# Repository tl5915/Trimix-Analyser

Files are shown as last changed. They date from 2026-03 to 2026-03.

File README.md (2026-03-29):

# Trimix Analyser
Trimix analyser for scuba diving

## Material
### Housing
- Electronic junction box 158x90x60mm
- 15 mm ID, 18 mm OD PVC pipe (for sensor chamber, O2 mount to the end, He and CO on two sides, gas out on the other end)
- M16 x 1.0 tap (for O2 sensor)
- 16 mm ID silicone plug (drill hole for gas out)
- BCD nipple to 1.4 NPT male convertor (gas in)
- 3/8 UNF tap (tap on the NPT side of the above convertor to mount a o-ring-removed LP blanking plug to adjust flow rate to 2 L/min)
- 1/4 NPT female to the smallest hose barb you can find, use barb convertor if necessary (ideally 2 mm ID silicone tubing connect to sensor chamber)
### Electronics
- Oxygen sensor, Aux or Molex connector He Sensor
- Wisen MD62 Helium sensor (mount to sensor chamber with hole cut out and seal with epoxy)
- 1N5819 Schottky diode (drops the 3.3v to 3.0v that MD62 requires)
- DS3502 digital potentiometer (10k ohm), parallel connect to 510 ohm resistor to drop total resistence to 485 ohm
- 2k ohm resistors for MD62 wheastone bridge
- 47k ohm 1:1 voltage divider to monitor MD62 Vcc Gas Quality Sensor
- SGP40 gas sensor (drill hole to fit sensor into sensor chamber, seal with epoxy)
- Use JST-SH cable to connect to DS3502, provides power and I2C communication MCU and Display
- Seeed Xiao ESP32C3
- 1.3 inch I2C SH1106 OLED
- ADS1115 ADC
### Power
- 3.7V 2000 mAh LiPo battery
- TP4056 LiPo charging board
- Qi wireless charging receiver unit
- Sparkfun Soft Power Switch (connect to external momentary button, connect push and off to GPIO pins)
- Momentary button for calibration and power
- 3.3V buck-boost converter (at least 250mA output capacity)
- 100nF capacitors at converter input and output
- 47k ohm 1:1 voltage divider to monitor battery voltage

## Button logic
- Press and hold button for 1 second to power on
- In main page, single press to enter menu
- Short press to toggle, long press to select
- Press and hold for 5 seconds to power off
- Press and hold for 10 seconds will force the switch to hardware power off
- Automatic power off after 5 minutes if no button press

## WiFi
- Default off to save power, can be turned on in setting menu
- Connect WiFi hotspot and scan the QR code to see more data, maunally input calibration values, and OTA firmware upgrade
- WiFi transmission power is set to minimum, external antenna must be connected

## Usage
- Reverse helium polarity in setting menu if helium voltage is negative in trimix
- Use pure helium or standard gas trimix for helium calibration
- SGP40 reading at top middle of the display, only shows after 1 minute initialisation. This reading is not in PPM, but relative to fresh air (100), lower (towards 1) the better quality, higher (towards 500) the worse quality. Volatile organic compounds, CO, and CO2 (all gases you don't want in your cylinder) increases reading
- Connect to WiFi, scan QR code to open web page
- More sensor informations can be found on web page, also allow maunal overwrite of calibration values
- Upload .bin file for OTA firmware update

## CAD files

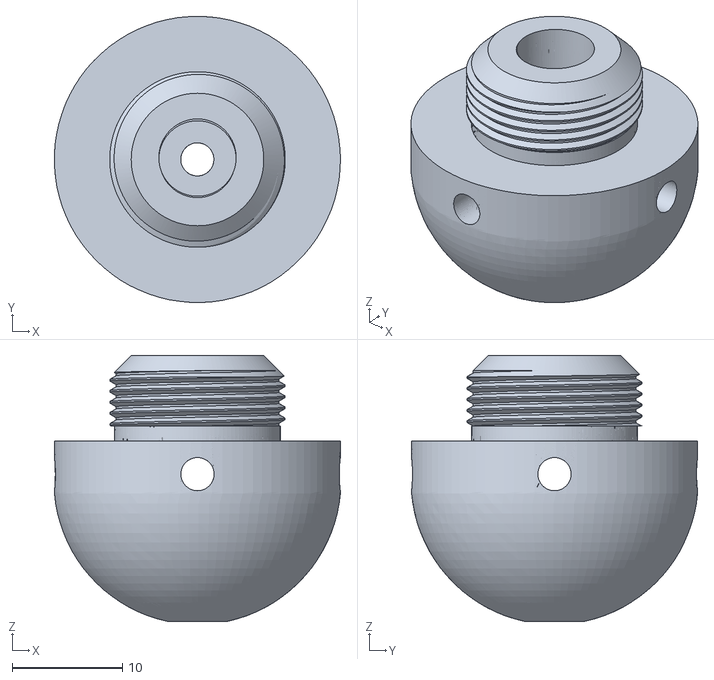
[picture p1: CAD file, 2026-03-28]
Flow_restrictor.stl
25.9 x 25.9 x 24.1

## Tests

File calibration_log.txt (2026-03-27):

Calibration Log with known standard gas:
===============

12/67: 6.1mV / 371.7mV

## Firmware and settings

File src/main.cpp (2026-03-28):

#include <Arduino.h>
// OTA & UI Libraries
#include <WiFi.h>
#include <Update.h>
#include <esp_bt.h>
#include <esp_wifi.h>
#include <WebServer.h>
// Peripheral Libraries
#include <EEPROM.h>
#include <Adafruit_GFX.h>
#include <Adafruit_SH110X.h>
#include <Adafruit_DS3502.h>
#include <Adafruit_ADS1X15.h>
#include <SparkFun_SGP40_Arduino_Library.h>
#include <sensirion_arch_config.h>
#include <sensirion_voc_algorithm.h>
// HTML Pages
#include "html_page.h"
#include "manual_calibration_page.h"
// Bitmaps
#include "qr_code_bitmap.h"
#include "wifi_logo.h"

// Forward Declarations
void powerOffMode();
void airOxygenCalibration();
void zeroHeliumCalibration();
void pureOxygenCalibration();
void performHeliumCalibration();
void calibrationDisplay();
void resetToDefaultCalibration();
void enterSettingMode();
void setOxygenCalibration();
void setHeliumCalibration();
void setHeliumPolarity();
void setWiFi();
float getOxygenVoltage();
float getHeliumVoltage();

// Global Objects
SGP40 sgp40;
Adafruit_DS3502 ds3502;
Adafruit_ADS1115 ads;
Adafruit_SH1106G display(128, 64, &Wire);

// Pin Definition
const uint8_t SCLPin = D6;        // GPIO21, SCL
const uint8_t SDAPin = D5;        // GPIO 7, SDA
const uint8_t ADDRPin = D4;       // GPIO 6, ADS1115 Address
const uint8_t powerPin = D3;      // GPIO 5, Power off
const uint8_t batteryPin = A2;    // GPIO 4, Battery monitoring
const uint8_t MD62VccPin = A1;    // GPIO 3, MD62 input voltage monitoring
const uint8_t calButtonPin = D0;  // GPIO 2, Calibration button

// EEPROM Address
const int ADDR_HELIUM_POLARITY = 0;
const int ADDR_WIPER_VALUE = 4;
const int ADDR_OXYGEN_CAL_PERCENTAGE = 8;
const int ADDR_HELIUM_CAL_PERCENTAGE = 12;
const int ADDR_OXYGEN_CAL_VOLTAGE = 16;
const int ADDR_PURE_OXYGEN_VOLTAGE = 24;
const int ADDR_HELIUM_CAL_VOLTAGE = 32;
const int ADDR_WIFI_STATUS = 40;

// Calibration
const uint8_t defaultwiperValue = 57;           // Potentiometer wiper position
const uint8_t defaultOxygenCalPercentage = 99;  // Oxygen calibration percentage
const uint8_t defaultHeliumCalPercentage = 67;  // Helium calibration percentage
const float defaultOxygenCalVoltage = 9.38;     // Oxygen voltage in air
const float defaultPureOxygenVoltage = 49.75;     // Oxygen voltage in oxygen
const float defaultHeliumCalVoltage = 382.01;    // Helium voltage in helium
bool heliumPolarity = false;
bool isTwoPointCalibrated = false;
uint8_t wiperValue = defaultwiperValue;
uint8_t bestWiperValue = wiperValue;
uint8_t OxygenCalPercentage = defaultOxygenCalPercentage; 
uint8_t HeliumCalPercentage = defaultHeliumCalPercentage;
float oxygencalVoltage = defaultOxygenCalVoltage;
float pureoxygenVoltage = defaultPureOxygenVoltage;
float heliumcalVoltage = defaultHeliumCalVoltage;

// Sampling
const uint8_t calibrationSampleCount = 20;  // Average 20 samples for calibration
const uint8_t samplingRateHz = 50;          // Sampling rate 50 Hz
const uint8_t displayRateHz = 2;            // Display refresh rate 2 Hz
unsigned long lastSampleTime = 0;
unsigned long lastDisplayUpdate = 0;
uint16_t voc = 0;
uint16_t sgpRaw = 0;
uint16_t sgpRawCorr = 0;
uint16_t sampleCount = 0;
uint16_t avgSampleCount = 0;
float oxygenVoltage = 0.0;
float oxygenSum = 0.0;
float avgOxygenVoltage = 0.0;
float oxygenPercentage = 0.0;
float heliumVoltage = 0.0;
float heliumSum = 0.0;
float avgHeliumVoltage = 0.0;
float correctedHeliumVoltage = 0.0;
float heliumPercentage = 0.0;
float MD62Voltage = 0.0;
float MD62Sum = 0.0;
float avgMD62Voltage = 0.0;
float batteryVoltage = 0.0;
float batterySum = 0.0;
float avgBatteryVoltage = 0.0;
uint8_t batteryPercentage = 0;
uint16_t mod14 = 0;
uint16_t mod16 = 0;
uint16_t end = 0;
float den = 0.0;
bool sixnine = false;
unsigned long sixnineStartTime = 0;

// Calibration Button
const unsigned long debounceDelay = 50;        // Button debounce delay 50 ms
const unsigned long decisionWindow = 799;      // Short press threshold 799 ms
const unsigned long longPressDuration = 800;   // Long press threshold 800 ms
const unsigned long powerOffDuration = 3000;   // Power off threshold 3000 ms
const unsigned long powerOnDuration = 1000;    // Power on threshold 1000 ms
const unsigned long timeOutDuration = 900000;  // Power time out threshold 15 min
unsigned long lastButtonDebounceTime = 0;
unsigned long buttonPressStartTime = 0;
unsigned long lastButtonPressTime = 0;
bool isButtonPressed = false;
bool isShortPress = false;
bool isLongPress = false;
bool isPowerOff = false;
bool lastButtonState = false;

// WiFi Settings
const char *ssid = "trimix_analyser";  // WiFi SSID
const char *password = "12345678";     // WiFi password
WebServer server(80);                  // Web server on port 80
bool wifiEnabled = false;              // WiFi default off


// Calibration Button State
void checkCalibrationButton() {
  unsigned long currentTime = millis();
  bool currentButtonState = digitalRead(calButtonPin) == LOW;

  if (currentButtonState != lastButtonState) {
    lastButtonDebounceTime = currentTime;  // Reset debounce timer
  }

  if ((currentTime - lastButtonDebounceTime) > debounceDelay) {  // Button debounce
    if (currentButtonState) {  // Button pressed
      if (!isButtonPressed) {  // New press detected
        buttonPressStartTime = currentTime;
        isButtonPressed = true;
        isShortPress = false;
        isLongPress = false;
        isPowerOff = false;
      } else if (!isLongPress && (currentTime - buttonPressStartTime >= longPressDuration)) {  // Long press
        isShortPress = false;
        isLongPress = true;
        isPowerOff = false;
      } else if (!isPowerOff && (currentTime - buttonPressStartTime >= powerOffDuration)) {  // Power off
        isShortPress = false;
        isLongPress = false;
        isPowerOff = true;
        powerOffMode();
      }
    } else {  // Button is released
      if (isButtonPressed) {
        isButtonPressed = false;
        if (!isLongPress && (currentTime - buttonPressStartTime) <= decisionWindow) {  // Short press
          isShortPress = true;
        }
      }
    }
  }
  lastButtonState = currentButtonState;
}

// Calibration Mode
uint8_t calibrationOption = 0;
bool inCalibrationMode = false;
const uint8_t numCalibrationOptions = 8;
String getCalibrationOption(uint8_t index) {
  switch (index) {
    case 0: return "21% O2";
    case 1: return "0% He";
    case 2: return String(OxygenCalPercentage) + "% O2";
    case 3: return String(HeliumCalPercentage) + "% He";
    case 4: return "View";
    case 5: return "Reset";
    case 6: return "Setting";
    case 7: return "Exit";
    default: return "";
  }
}

void enterCalibrationMode() {
  isShortPress = false;
  isLongPress = false;
  inCalibrationMode = true;
  calibrationOption = 0;

  display.clearDisplay();
  display.setTextSize(2);
  display.setCursor(10, 24);
  display.print(F("Calibrate"));
  display.display();
  delay(500);

  while (inCalibrationMode) {
    display.clearDisplay();
    display.setTextSize(2);
    display.setCursor(10, 0);
    display.print(F("Calibrate"));
    display.drawLine(0, 18, 128, 18, SH110X_WHITE);

    display.setTextSize(1);
    for (uint8_t i = 0; i < numCalibrationOptions; i++) {
      if (i < 4) {  // Left column
        display.setCursor(0, 24 + (i * 10));
      } else {      // Right column
        display.setCursor(64, 24 + ((i - 4) * 10));
      }
      if (i == calibrationOption) {
        display.print(F("> "));
      } else {
        display.print(F("  "));
      }
      display.print(getCalibrationOption(i));
    }
    display.display();

    checkCalibrationButton();

    if (isShortPress) {        // Short press to move to next option
      isShortPress = false;
      calibrationOption = (calibrationOption + 1) % numCalibrationOptions;
    } else if (isLongPress) {  // Long press to select option
      isLongPress = false;
      switch (calibrationOption) {
        case 0:
          airOxygenCalibration();       // Perform 21% oxygen calibration
          break;
        case 1:
          zeroHeliumCalibration();      // Perform 0% helium calibration
          break;
        case 2:
          pureOxygenCalibration();      // Perform 100% oxygen calibration
          break;
        case 3:
          performHeliumCalibration();   // Perform 100% helium calibration
          break;
        case 4:
          calibrationDisplay();         // View calibration values
          break;
        case 5:
          resetToDefaultCalibration();  // Reset all calibrations
          break;
        case 6:
          enterSettingMode();           // Enter setting mode
          break;
        case 7:
          inCalibrationMode = false;    // Exit calibration mode
          break;
      }
    }
  }
}

// Calibration Mode - 21% Oxygen Calibration
void airOxygenCalibration() {
  while (true) {
    display.clearDisplay();
    display.setTextSize(1);
    display.setCursor(8, 18);
    display.print(F("21% Oxygen"));
    display.setCursor(8, 38);
    display.print(F("Calibrating..."));
    display.display();

    oxygenSum = 0.0;
    for (uint8_t i = 0; i < calibrationSampleCount; i++) {
      oxygenVoltage = getOxygenVoltage();
      oxygenSum += oxygenVoltage;
      delay(20);  // 50 Hz sampling rate
    }
    oxygencalVoltage = oxygenSum / calibrationSampleCount;

    display.clearDisplay();
    display.setTextSize(1);
    display.setCursor(8, 18);
    display.print(F("21% O2 Calibration"));
    display.setCursor(8, 38);
    display.print(oxygencalVoltage, 2);
    display.print(F(" mV"));
    display.display();

    while (true) {
      checkCalibrationButton();

      if (isShortPress) {        // Short press to repeat calibration
        isShortPress = false;
        break; 
      } else if (isLongPress) {  // Long press to save calibration
        isLongPress = false;

        EEPROM.put(ADDR_OXYGEN_CAL_VOLTAGE, oxygencalVoltage);
        EEPROM.commit();

        display.clearDisplay();
        display.setTextSize(1);
        display.setCursor(8, 28);
        display.print(F("Calibration Saved"));
        display.display();
        delay(500);

        inCalibrationMode = false;
        return;  // Exit calibration after saving
      }
    }
  }
}

// Calibration Mode - 100% Oxygen Calibration
void pureOxygenCalibration() {
  while (true) {
    display.clearDisplay();
    display.setTextSize(1);
    display.setCursor(8, 18);
    display.print(OxygenCalPercentage);
    display.print(F("% Oxygen"));
    display.setCursor(8, 38);
    display.print(F("Calibrating..."));
    display.display();

    oxygenSum = 0.0;
    for (uint8_t i = 0; i < calibrationSampleCount; i++) {
      oxygenVoltage = getOxygenVoltage();
      oxygenSum += oxygenVoltage;
      delay(20);  // 50 Hz sampling rate
    }
    pureoxygenVoltage = oxygenSum / calibrationSampleCount;

    if (pureoxygenVoltage <= oxygencalVoltage) {  // Invalid calibration
      while (true) {
        display.clearDisplay();
        display.setTextSize(2);
        display.setCursor(28, 20);
        display.print(F("Failed"));
        display.setTextSize(1);
        display.setCursor(22, 54);
        display.print(F("O2 Voltage Low"));
        display.display();

        checkCalibrationButton();
    
        if (isShortPress) {        // Short press to repeat calibration
          isShortPress = false;
          break;
        } else if (isLongPress) {  // Long press to exit without saving
          isLongPress = false;
          inCalibrationMode = false;
          return;
        }
      }
    } else {  // Valid calibration
      display.clearDisplay();
      display.setTextSize(1);
      display.setCursor(8, 18);
      display.print(OxygenCalPercentage);
      display.print(F("% O2 Calibration"));
      display.setCursor(8, 38);
      display.print(pureoxygenVoltage, 2);
      display.print(F(" mV"));
      display.display();
      
      while (true) {
        checkCalibrationButton();

        if (isShortPress) {        // Short press to repeat calibration
          isShortPress = false;
          break;
        } else if (isLongPress) {  // Long press to save calibration
          isLongPress = false;

          EEPROM.put(ADDR_PURE_OXYGEN_VOLTAGE, pureoxygenVoltage);
          EEPROM.commit();
          isTwoPointCalibrated = true;

          display.clearDisplay();
          display.setTextSize(1);
          display.setCursor(8, 28);
          display.print(F("Calibration Saved"));
          display.display();
          delay(500);

          inCalibrationMode = false;
          return;  // Exit calibration after saving
        }
      }
    }
  }
}
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
void loop() {
  unsigned long currentTime = millis();
  
  // HTML update
  if (wifiEnabled) {
    server.handleClient();
  }

  // Button state
  checkCalibrationButton();
  if (isShortPress) {
    isShortPress = false;
    enterCalibrationMode();  // Short press to enter calibration mode
  } else if (isPowerOff) {
    isPowerOff = false;
    powerOffMode();          // Hold to power off
  }
  
  // Auto shut down
  if (currentTime - lastButtonPressTime >= timeOutDuration) {
    for (uint8_t countDown = 5; countDown > 0; countDown--) {
      unsigned long countdownStart = millis();
      while (millis() - countdownStart < 1000) {
        checkCalibrationButton();
        if (isButtonPressed) {
          lastButtonPressTime = millis();
          return;
        }
      }
      display.clearDisplay();
      display.setTextSize(2);
      display.setCursor(10, 12);
      display.print(F("Power Off"));
      display.setCursor(58, 36);
      display.print(countDown);
      display.display();
    }
    digitalWrite(powerPin, HIGH);
  }

  // Low battery protection at 3.2 V
  if (currentTime >= 5000 && avgBatteryVoltage < 3.2) {
    display.clearDisplay();
    display.setTextSize(2);
    display.setCursor(16, 12);
    display.print(F("Batt Low"));
    display.setCursor(10, 36);
    display.print(F("Power Off"));
    display.display();
    delay(500);
    digitalWrite(powerPin, HIGH);
  }  

  // Sensor sampling
  if (currentTime - lastSampleTime >= (1000 / samplingRateHz)) {
    lastSampleTime = currentTime;
    if (sampleCount == 0) {
      oxygenSum = heliumSum = MD62Sum = batterySum = 0.0;
    }
    oxygenVoltage = getOxygenVoltage();
    oxygenSum += oxygenVoltage;
    heliumVoltage = getHeliumVoltage();
    heliumSum += heliumVoltage;
    MD62Voltage = analogReadMilliVolts(MD62VccPin) / 1000.0 * 2.0;     // MD62 Vcc voltage, 1:1 divider
    MD62Sum += MD62Voltage;
    batteryVoltage = analogReadMilliVolts(batteryPin) / 1000.0 * 2.05;  // Battery voltage, 1:1 divider with offset
    batterySum += batteryVoltage;
    sampleCount++;
  }

  // Update cycle
  if (!isButtonPressed && currentTime - lastDisplayUpdate >= (1000 / displayRateHz)) {
    lastDisplayUpdate = currentTime;

    // Calculate average voltages
    avgOxygenVoltage = (sampleCount > 0) ? (oxygenSum / sampleCount) : 0.0;
    if (avgOxygenVoltage > 99.9) {
      avgOxygenVoltage = 99.9;   // Maximum oxygen voltage allowed 99.9 mV
    }
    avgHeliumVoltage = (sampleCount > 0) ? (heliumSum / sampleCount) : 0.0;
    avgMD62Voltage = (sampleCount > 0) ? (MD62Sum / sampleCount) : 0.0;
    if (avgMD62Voltage > 9.99) {
      avgMD62Voltage = 9.99;     // Maximum MD62 Vcc voltage allowed 9.99 V
    }
    avgBatteryVoltage = (sampleCount > 0) ? (batterySum / sampleCount) : 0.0;
    if (avgBatteryVoltage > 9.99) {
      avgBatteryVoltage = 9.99;  // Maximum battery voltage allowed 9.99 V
    }
    avgSampleCount = sampleCount;
    sampleCount = 0;

    // Calculate oxygen percentage
    oxygenPercentage = getOxygenPercentage();
    bool oxygenWarning = false;
    if (oxygenPercentage < 0.0) {
      oxygenPercentage = 0.0;  // Minimum oxygen percentage allowed 0%
    } else if (oxygenPercentage > 99.9) {
    oxygenPercentage = 99.9;   // Maximum oxygen percentage allowed 99.9%
    oxygenWarning = true;      // Warning if oxygen percentage exceed 99.9%
    }
    if (oxygenPercentage >= 69.0 && oxygenPercentage < 69.5) {
      if (!sixnine) {
        sixnine = true;
        sixnineStartTime = currentTime;
      } else if (currentTime - sixnineStartTime >= 2000) {
        display.clearDisplay();
        display.setTextSize(3);
        display.setCursor(28, 20);
        display.print(F("Nice"));
        display.display();
        delay(1000);
        sixnine = false;
      }
    } else {
      sixnine = false;
    }

    // Calculate helium percentage
    correctedHeliumVoltage = avgHeliumVoltage - (17.0 / (1 + exp(-0.105 * (oxygenPercentage - 52.095))));  // Helium correction factor based on oxygen percentage
    if (correctedHeliumVoltage > 999.9) {
      correctedHeliumVoltage = 999.9;   // Maximum helium voltage allowed 999.9 mV
    } else if (correctedHeliumVoltage < -999.0) {
      correctedHeliumVoltage = -999.0;  // Minimum helium voltage allowed -999.0 mV if helium sensor polarity is inverted
    }    
    heliumPercentage = (correctedHeliumVoltage > 0.0) ? (correctedHeliumVoltage / heliumcalVoltage) * HeliumCalPercentage : 0.0;
    bool heliumWarning = false;
    if (heliumPercentage < 2.0) {
      heliumPercentage = 0.0;  // Minimum helium percentage allowed 0%, treat <2% as 0%
    } else if (heliumPercentage > 99.9) {
    heliumPercentage = 99.9;   // Maximum helium percentage allowed 99.9%
    heliumWarning = true;      // Warning if helium percentage exceed 99.9%
    }

    // Calculate MOD
    mod14 = (oxygenPercentage > 0) ? (int)((1400.0 / oxygenPercentage) - 10.0) : 0;  // MOD at ppO2 1.4
    if (mod14 > 999) {
      mod14 = 999;  // Maximum MOD allowed 999 m
    }
    mod16 = (oxygenPercentage > 0) ? (int)((1600.0 / oxygenPercentage) - 10.0) : 0;  // MOD at ppO2 1.6
    if (mod16 > 999) {
      mod16 = 999;  // Maximum MOD allowed 999 m
    }

    // Calculate END
    end = (mod14 + 10.0) * (1 - heliumPercentage / 100.0) - 10.0;  // END at MOD 1.4
    if (end < 0) {
      end = 0;  // Minimum END allowed 0 m
    }

    // Calculate Density
    den = (oxygenPercentage * 0.1756 - heliumPercentage * 1.0582 + 123.46) * (mod14 + 10) / 1000;  // Density at MOD 1.4
    if (den > 99.9) {
      den = 99.9;  // Maximum density allowed 99.9 g/L
    }

    // Calculate battery percentage
    batteryPercentage = round(123 - (123 / pow((1 + pow((avgBatteryVoltage / 3.61), 80)), 0.165)));  // Battery percentage
    if (batteryPercentage > 100) {
      batteryPercentage = 100;  // Maximum battery percentage allowed 100%
    }

    // Get Time
    String elapsedTime = formatTime();

    // Get Gas Quality, 0% humidity, 20 degree Celsius
    voc = sgp40.getVOCindex(0, 20);    // VOC index
    if (voc < 1) {
      voc = 1;                         // VOC index minimum 1
    } else if (voc > 500) {
      voc = 500;                       // VOC index maximum 500
    }
    String vocStr = "(" + String(voc) + ")";
    uint8_t vocStrX = (128 - vocStr.length() * 6) / 2;
    sgp40.measureRaw(&sgpRaw, 0, 20);  // Raw reading
    if (sgpRaw < 20001) {
      sgpRaw = 20001;                  // Raw reading minimum 20001
    } else if (sgpRaw > 52767) {
      sgpRaw = 52767;                  // Raw reading maximum 52767
    }
    sgpRawCorr = sgpRaw - 20000;       // Corrected range 1-32767

    // Display
    display.clearDisplay();

    display.setTextSize(1);
    display.setCursor(0, 0);
    display.print(elapsedTime);

    if (currentTime >= 60000) {
      display.setCursor(vocStrX, 0);
      display.print(vocStr);
    } else {
      display.setCursor(55, 0);
      display.print(F("(-)"));
    }

    if (wifiEnabled) {
      display.drawBitmap(90, 0, wifiLogo, 16, 8, SH110X_WHITE);
    }

    display.drawRect(106, 0, 20, 8, SH110X_WHITE); // Main battery rectangle
    display.fillRect(126, 3, 2, 2, SH110X_WHITE); // Battery tip
    int16_t fillWidth = map(batteryPercentage, 0, 100, 0, 16); // Percentage to fill
    display.fillRect(108, 2, fillWidth, 4, SH110X_WHITE);  // Fill battery indicator

    display.setTextSize(2);
    display.setCursor(0, 12);
    if (oxygenPercentage < 9.95) {
      display.print(F(" "));
    }
    display.print(oxygenPercentage, 1);
    if (oxygenWarning) {
      display.print(F("!"));
    }
    display.setCursor(58, 12);
    display.print(F("/"));
    if (heliumWarning) {
      display.print(F("!"));
    }
    display.setCursor(80, 12);
    if (heliumPercentage < 9.95) {
      display.print(F(" "));
    }
    display.print(heliumPercentage, 1);

    display.setTextSize(1);
    display.setCursor(0, 34);
    display.print(F("O2:"));  
    display.print(avgOxygenVoltage, 1);
    display.print(F("mV"));

    display.setCursor(68, 34);
    display.print(F("He:"));
    if (correctedHeliumVoltage <= -99.95) {
      display.print(correctedHeliumVoltage, 0);
    } else {
      display.print(correctedHeliumVoltage, 1);
    }
    display.print(F("mV"));

    display.setCursor(0, 46);
    display.print(F("MOD:"));
    display.print(mod14);
    display.print(F("/"));
    display.print(mod16);
    display.print(F("m"));

    display.setCursor(0, 56);
    display.print(F("END:"));
    display.print(end);
    display.print(F("m"));

    display.setCursor(80, 46);
    display.print(F("Density:"));
    display.setCursor(86, 56);
    display.print(den, 1);
    display.print(F("g/L"));
    display.display();
  }
}

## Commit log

2026-03-27 Added O2 Humidity Compensation.csv
    [O2 Humidity Compensation.csv]
2026-03-28 Include data sheets
    [O2 Humidity Compensation.csv]
2026-03-28 Add flow restrictor STL file
    [Flow_restrictor.stl]
2026-03-28 Improve button short press timing
    [main.cpp]
